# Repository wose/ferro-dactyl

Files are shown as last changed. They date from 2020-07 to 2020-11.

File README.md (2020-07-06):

# Ferro Dactyl

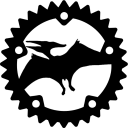
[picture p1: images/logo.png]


> A BluePill (STM32F103) based [Dactyl-Manuform] build with [keyberon] powered
> firmware written in Rust. 

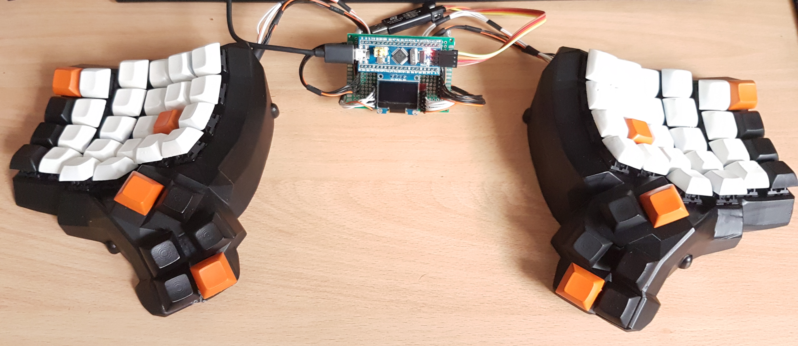
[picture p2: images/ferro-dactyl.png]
Ferro Dactyl


[Dactyl-Manuform]: https://github.com/20lives/Dactyl-Manuform
[keyberon]: https://github.com/TeXitoi/keyberon

## Layout

I'm using a [AdNW] based Layout. This is a work in progress.

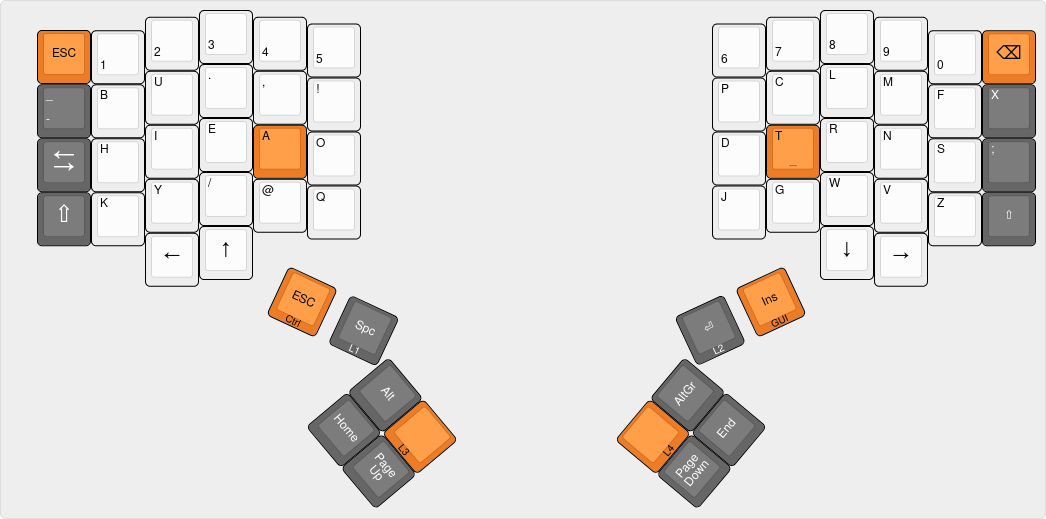
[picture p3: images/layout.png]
Layout


You can take the layout definition from the [layout folder] and play with it
over at [Keyboard Layout Editor]. Or use [this link].

[AdNW]: http://www.adnw.de/
[layout folder]:layout/
[Keyboard Layout Editor]: http://www.keyboard-layout-editor.com/
[this link]: http://www.keyboard-layout-editor.com/#/gists/5a7d56aa6b7ebb05c0e3928ac5250a80

## Hardware

The [STLs] are generated using [20lives Dactyl-Manuform fork]. I'm using a 5x6
version.

[STLs]: stl/
[20lives Dactyl-Manuform fork]:  https://github.com/20lives/Dactyl-Manuform

## Firmware

The firmware uses the [keyberon] library.

```shell
curl https://sh.rustup.rs -sSf | sh
rustup target add thumbv7m-none-eabi
sudo apt-get install gdb-arm-none-eabi openocd
git clone https://github.com/wose/ferro-dactyl.git
cd ferro-dactyl
# connect ST-Link v2 to the blue pill and the computer
# openocd in another terminal
cargo run --release
```
See `keyberons` [building instructions] for more info.

[building instructions]: https://github.com/TeXitoi/keyberon/blob/master/BUILDING.md

## License

Licensed under either of

- Apache License, Version 2.0 ([LICENSE-APACHE](LICENSE-APACHE) or
  http://www.apache.org/licenses/LICENSE-2.0)
- MIT license ([LICENSE-MIT](LICENSE-MIT) or http://opensource.org/licenses/MIT)

at your option.

### Contribution

Unless you explicitly state otherwise, any contribution intentionally submitted
for inclusion in the work by you, as defined in the Apache-2.0 license, shall be
dual licensed as above, without any additional terms or conditions.

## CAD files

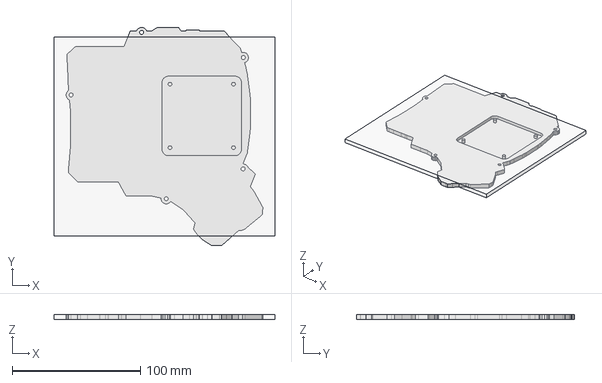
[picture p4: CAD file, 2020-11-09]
freecad/base.FCStd
172.4 x 170.4 x 4.00 mm
Stock001

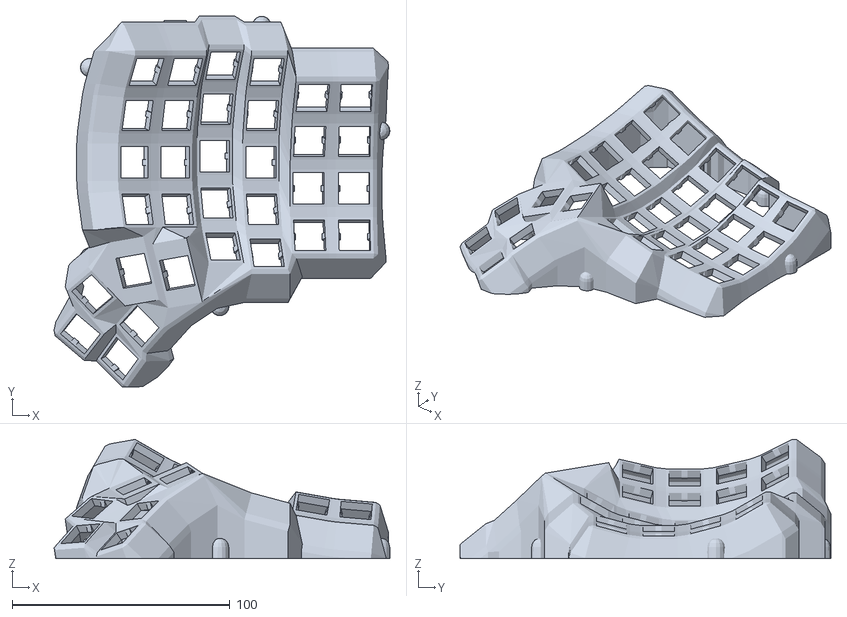
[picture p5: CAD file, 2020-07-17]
stl/right.stl
154.4 x 170.6 x 54.8

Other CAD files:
stl/left.stl

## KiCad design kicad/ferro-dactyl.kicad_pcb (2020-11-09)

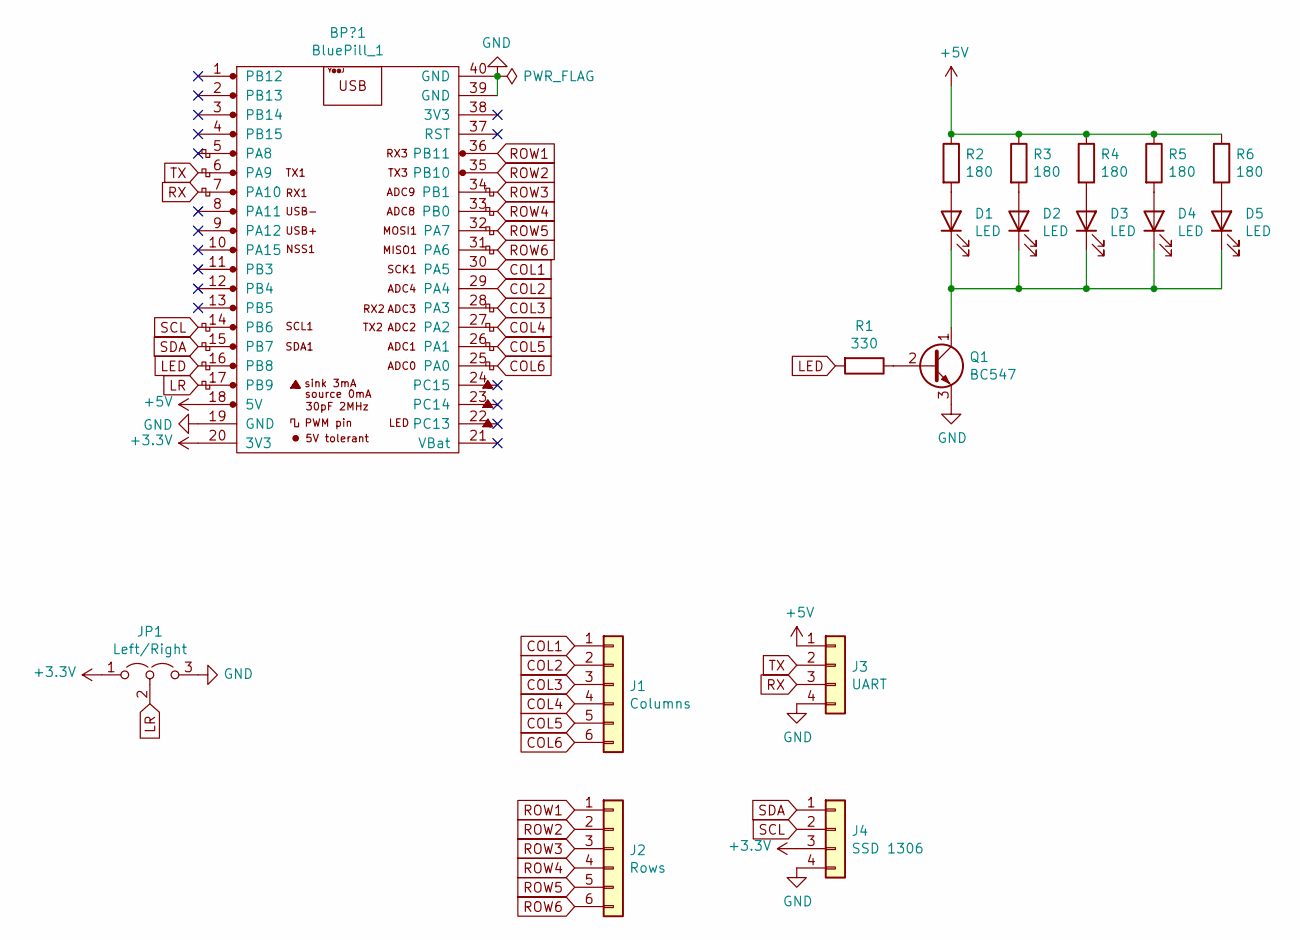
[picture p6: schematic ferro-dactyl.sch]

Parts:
BP?1: BluePill_1; YAAJ_BluePill_SWD_1
D1, D2, D3, D4, D5: LED; PinSocket_1x02_P2.54mm_Vertical
J1: Columns; PinSocket_1x06_P2.54mm_Vertical
J2: Rows; PinSocket_1x06_P2.54mm_Vertical
J3: UART; PinSocket_1x04_P2.54mm_Vertical
J4: SSD 1306; PinSocket_1x04_P2.54mm_Vertical
JP1: Left/Right; PinHeader_1x03_P2.54mm_Vertical
Q1: BC547; TO-92_Inline
R1: 330; R_Axial_DIN0411_L9.9mm_D3.6mm_P12.70mm_Horizontal
R2, R3, R4, R5, R6: 180; R_Axial_DIN0411_L9.9mm_D3.6mm_P12.70mm_Horizontal

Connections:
+3V3: BP?1.20 (3V3), J4.3, JP1.1 (A)
+5V: BP?1.18 (5V), J3.1, R2.1, R3.1, R4.1, R5.1, R6.1
COL1: BP?1.30 (PA5), J1.1
COL2: BP?1.29 (PA4), J1.2
COL3: BP?1.28 (PA3), J1.3
COL4: BP?1.27 (PA2), J1.4
COL5: BP?1.26 (PA1), J1.5
COL6: BP?1.25 (PA0), J1.6
GND: BP?1.19 (GND), BP?1.39 (GND), BP?1.40 (GND), J3.4, J4.4, JP1.3 (B), Q1.3 (E)
LED: BP?1.16 (PB8), R1.2
LR: BP?1.17 (PB9), JP1.2 (C)
unnamed: D1.1 (K), D2.1 (K), D3.1 (K), D4.1 (K), D5.1 (K), Q1.1 (C)
unnamed: D1.2 (A), R2.2
unnamed: D2.2 (A), R3.2
unnamed: D3.2 (A), R4.2
unnamed: D4.2 (A), R5.2
unnamed: D5.2 (A), R6.2
unnamed: Q1.2 (B), R1.1
ROW1: BP?1.36 (PB11), J2.1
ROW2: BP?1.35 (PB10), J2.2
ROW3: BP?1.34 (PB1), J2.3
ROW4: BP?1.33 (PB0), J2.4
ROW5: BP?1.32 (PA7), J2.5
ROW6: BP?1.31 (PA6), J2.6
RX: BP?1.7 (PA10), J3.3
SCL: BP?1.14 (PB6), J4.2
SDA: BP?1.15 (PB7), J4.1
TX: BP?1.6 (PA9), J3.2

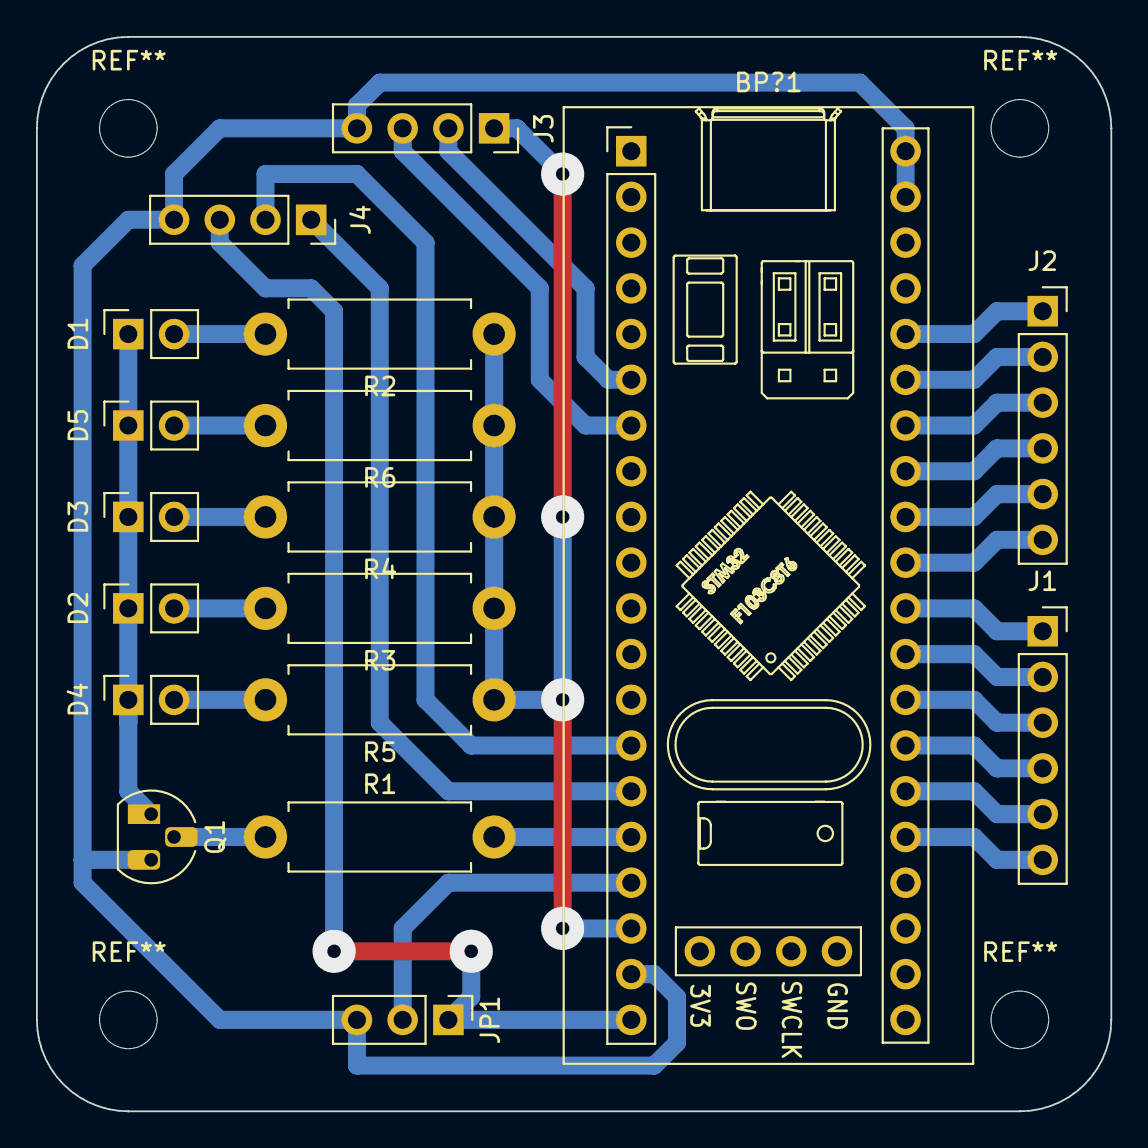
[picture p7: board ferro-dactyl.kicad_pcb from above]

Board: 2 copper layers, 59.7 x 59.7 mm, 18 parts (0 on the bottom side), 28 nets.

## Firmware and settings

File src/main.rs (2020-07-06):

#![no_main]
#![no_std]

use core::convert::Infallible;
use embedded_hal::digital::v2::{InputPin, OutputPin};
use generic_array::typenum::{U12, U6};
use keyberon::action::Action::{self, *};
use keyberon::action::{d, k, l, m};
use keyberon::debounce::Debouncer;
use keyberon::impl_heterogenous_array;
use keyberon::key_code::KeyCode::*;
use keyberon::key_code::{KbHidReport, KeyCode};
use keyberon::layout::Layout;
use keyberon::matrix::{Matrix, PressedKeys};
use panic_semihosting as _;
use rtfm::app;
use stm32f1xx_hal::gpio::{gpioa::*, gpiob::*, Input, Output, PullUp, PushPull};
use stm32f1xx_hal::prelude::*;
use stm32f1xx_hal::usb::{Peripheral, UsbBus, UsbBusType};
use stm32f1xx_hal::{gpio, pac, timer};
use usb_device::bus::UsbBusAllocator;
use usb_device::class::UsbClass as _;

type UsbClass = keyberon::Class<'static, UsbBusType, Leds>;
type UsbDevice = keyberon::Device<'static, UsbBusType>;

pub struct Leds {
    caps_lock: gpio::gpioc::PC13<gpio::Output<gpio::PushPull>>,
}
impl keyberon::keyboard::Leds for Leds {
    fn caps_lock(&mut self, status: bool) {
        if status {
            self.caps_lock.set_low().unwrap()
        } else {
            self.caps_lock.set_high().unwrap()
        }
    }
}

pub struct Cols(
    pub PB12<Input<PullUp>>,
    pub PB13<Input<PullUp>>,
    pub PB14<Input<PullUp>>,
    pub PB15<Input<PullUp>>,
    pub PA8<Input<PullUp>>,
    pub PA9<Input<PullUp>>,
    pub PA0<Input<PullUp>>,
    pub PA1<Input<PullUp>>,
    pub PA2<Input<PullUp>>,
    pub PA3<Input<PullUp>>,
    pub PA4<Input<PullUp>>,
    pub PA5<Input<PullUp>>,
);
impl_heterogenous_array! {
    Cols,
    dyn InputPin<Error = Infallible>,
    U12,
    [0, 1, 2, 3, 4, 5, 6, 7, 8, 9, 10, 11]
}

pub struct Rows(
    pub PB11<Output<PushPull>>,
    pub PB10<Output<PushPull>>,
    pub PB1<Output<PushPull>>,
    pub PB0<Output<PushPull>>,
    pub PA7<Output<PushPull>>,
    pub PA6<Output<PushPull>>,
);
impl_heterogenous_array! {
    Rows,
    dyn OutputPin<Error = Infallible>,
    U6,
    [0, 1, 2, 3, 4, 5]
}

// layer keys
const L1_SPACE: Action = HoldTap {
    timeout: 200,
    hold: &l(1),
    tap: &k(Space),
};

const L2_ENTER: Action = HoldTap {
    timeout: 200,
    hold: &l(2),
    tap: &k(Enter),
};

const CTRL_ESCAPE: Action = HoldTap {
    timeout: 200,
    hold: &k(LCtrl),
    tap: &k(Escape),
};

const GUI_INSERT: Action = HoldTap {
    timeout: 200,
    hold: &k(LGui),
    tap: &k(Insert),
};

const ALTGR_DELETE: Action = HoldTap {
    timeout: 200,
    hold: &k(RAlt),
    tap: &k(Delete),
};

// shifted symbols
const TILD: Action = m(&[LShift, NonUsHash]);
const EXLM: Action = m(&[LShift, Kb1]);
const AT: Action = m(&[LShift, Kb2]);
const HASH: Action = m(&[LShift, Kb3]);
const DLR: Action = m(&[LShift, Kb4]);
const PERC: Action = m(&[LShift, Kb5]);
const CIRC: Action = m(&[LShift, Kb6]);
const AMPR: Action = m(&[LShift, Kb7]);
const ASTR: Action = m(&[LShift, Kb8]);
const LPRN: Action = m(&[LShift, Kb9]);
const RPRN: Action = m(&[LShift, Kb0]);
const UNDS: Action = m(&[LShift, Minus]);
const PLUS: Action = m(&[LShift, Equal]);
const LCBR: Action = m(&[LShift, LBracket]);
const RCBR: Action = m(&[LShift, RBracket]);
const LT: Action = m(&[LShift, Comma]);
const GT: Action = m(&[LShift, Dot]);
const COLN: Action = m(&[LShift, SColon]);
const PIPE: Action = m(&[LShift, Bslash]);
const QUES: Action = m(&[LShift, Slash]);
const DQUO: Action = m(&[LShift, Quote]);

#[rustfmt::skip]
pub static LAYERS: keyberon::layout::Layers = &[
    &[
        &[k(Escape), k(Kb1), k(Kb2),    k(Kb3),   k(Kb4),      k(Kb5),          k(Kb6),    k(Kb7),     k(Kb8),  k(Kb9),      k(Kb0),   k(BSpace)],
        &[k(Minus),  k(B),   k(U),      k(Dot),   k(Comma),    EXLM,            k(P),      k(C),       k(L),    k(M),        k(F),     k(X)],
        &[k(Tab),    k(H),   k(I),      k(E),     k(A),        k(O),            k(D),      k(T),       k(R),    k(N),        k(S),     COLN],
        &[k(LShift), k(K),   k(Y),      k(Slash), AT,          k(Q),            k(J),      k(G),       k(W),    k(V),        k(Z),     k(RShift)],
        &[NoOp,      NoOp,   k(Left),   k(Up),    CTRL_ESCAPE, L1_SPACE,        L2_ENTER,  GUI_INSERT, k(Down), k(Right),    NoOp,     NoOp],
        &[NoOp,      NoOp,   k(PgUp),   l(3),     k(Home),     k(LAlt),         k(RAlt),   k(End),     l(4),    k(PgDown), NoOp,     NoOp],
    ],
    &[
        &[Trans, Trans, Trans, Trans, Trans, Trans,        Trans, Trans, Trans, Trans, Trans, Trans],
        &[Trans, Trans, Trans, Trans, Trans, Trans,        Trans, Trans, Trans, Trans, Trans, Trans],
        &[Trans, Trans, Trans, Trans, Trans, Trans,        Trans, Trans, Trans, Trans, Trans, Trans],
        &[Trans, Trans, Trans, Trans, Trans, Trans,        Trans, Trans, Trans, Trans, Trans, Trans],
        &[NoOp,  NoOp,  Trans, Trans, Trans, Trans,        Trans, Trans, Trans, Trans, NoOp,  NoOp],
        &[NoOp,  NoOp,  Trans, Trans, Trans, Trans,        Trans, Trans, Trans, Trans, NoOp,  NoOp],
    ],
    &[
        &[Trans, Trans, Trans, Trans, Trans, Trans,        Trans, Trans, Trans, Trans, Trans, Trans],
        &[Trans, Trans, Trans, Trans, Trans, Trans,        Trans, Trans, Trans, Trans, Trans, Trans],
        &[Trans, Trans, Trans, Trans, Trans, Trans,        Trans, Trans, Trans, Trans, Trans, Trans],
        &[Trans, Trans, Trans, Trans, Trans, Trans,        Trans, Trans, Trans, Trans, Trans, Trans],
        &[NoOp,  NoOp,  Trans, Trans, Trans, Trans,        Trans, Trans, Trans, Trans, NoOp,  NoOp],
        &[NoOp,  NoOp,  Trans, Trans, Trans, Trans,        Trans, Trans, Trans, Trans, NoOp,  NoOp],
    ],
    &[
        &[Trans, Trans, Trans, Trans, Trans, Trans,        Trans, Trans, Trans, Trans, Trans, Trans],
        &[Trans, Trans, Trans, Trans, Trans, Trans,        Trans, Trans, Trans, Trans, Trans, Trans],
        &[Trans, Trans, Trans, Trans, Trans, Trans,        Trans, Trans, Trans, Trans, Trans, Trans],
        &[Trans, Trans, Trans, Trans, Trans, Trans,        Trans, Trans, Trans, Trans, Trans, Trans],
        &[NoOp,  NoOp,  Trans, Trans, Trans, Trans,        Trans, Trans, Trans, Trans, NoOp,  NoOp],
        &[NoOp,  NoOp,  Trans, Trans, Trans, Trans,        Trans, Trans, Trans, Trans, NoOp,  NoOp],
    ],
    &[
        &[Trans, Trans, Trans, Trans, Trans, Trans,        Trans, Trans, Trans, Trans, Trans, Trans],
        &[Trans, Trans, Trans, Trans, Trans, Trans,        Trans, Trans, Trans, Trans, Trans, Trans],
        &[Trans, Trans, Trans, Trans, Trans, Trans,        Trans, Trans, Trans, Trans, Trans, Trans],
        &[Trans, Trans, Trans, Trans, Trans, Trans,        Trans, Trans, Trans, Trans, Trans, Trans],
        &[NoOp,  NoOp,  Trans, Trans, Trans, Trans,        Trans, Trans, Trans, Trans, NoOp,  NoOp],
        &[NoOp,  NoOp,  Trans, Trans, Trans, Trans,        Trans, Trans, Trans, Trans, NoOp,  NoOp],
    ],
];

#[app(device = stm32f1xx_hal::pac, peripherals = true)]
const APP: () = {
    struct Resources {
        usb_dev: UsbDevice,
        usb_class: UsbClass,
        matrix: Matrix<Cols, Rows>,
        debouncer: Debouncer<PressedKeys<U6, U12>>,
        layout: Layout,
        timer: timer::CountDownTimer<pac::TIM3>,
    }

    #[init]
    fn init(c: init::Context) -> init::LateResources {
        static mut USB_BUS: Option<UsbBusAllocator<UsbBusType>> = None;

        let mut flash = c.device.FLASH.constrain();
        let mut rcc = c.device.RCC.constrain();

        let clocks = rcc
            .cfgr
            .use_hse(8.mhz())
            .sysclk(48.mhz())
            .pclk1(24.mhz())
            .freeze(&mut flash.acr);

        let mut gpioa = c.device.GPIOA.split(&mut rcc.apb2);
        let mut gpiob = c.device.GPIOB.split(&mut rcc.apb2);
        let mut gpioc = c.device.GPIOC.split(&mut rcc.apb2);

        let mut led = gpioc.pc13.into_push_pull_output(&mut gpioc.crh);
        led.set_high().unwrap();
        let leds = Leds { caps_lock: led };

        let usb_dm = gpioa.pa11;
        let usb_dp = gpioa.pa12.into_floating_input(&mut gpioa.crh);

        let usb = Peripheral {
            usb: c.device.USB,
            pin_dm: usb_dm,
            pin_dp: usb_dp,
        };

        *USB_BUS = Some(UsbBus::new(usb));
        let usb_bus = USB_BUS.as_ref().unwrap();

        let usb_class = keyberon::new_class(usb_bus, leds);
        let usb_dev = keyberon::new_device(usb_bus);

        let mut timer =
            timer::Timer::tim3(c.device.TIM3, &clocks, &mut rcc.apb1).start_count_down(1.khz());
        timer.listen(timer::Event::Update);

        let matrix = Matrix::new(
            Cols(
                gpiob.pb12.into_pull_up_input(&mut gpiob.crh),
                gpiob.pb13.into_pull_up_input(&mut gpiob.crh),
                gpiob.pb14.into_pull_up_input(&mut gpiob.crh),
                gpiob.pb15.into_pull_up_input(&mut gpiob.crh),
                gpioa.pa8.into_pull_up_input(&mut gpioa.crh),
                gpioa.pa9.into_pull_up_input(&mut gpioa.crh),

                gpioa.pa0.into_pull_up_input(&mut gpioa.crl),
                gpioa.pa1.into_pull_up_input(&mut gpioa.crl),
                gpioa.pa2.into_pull_up_input(&mut gpioa.crl),
                gpioa.pa3.into_pull_up_input(&mut gpioa.crl),
                gpioa.pa4.into_pull_up_input(&mut gpioa.crl),
                gpioa.pa5.into_pull_up_input(&mut gpioa.crl),
            ),
            Rows(
                gpiob.pb11.into_push_pull_output(&mut gpiob.crh),
                gpiob.pb10.into_push_pull_output(&mut gpiob.crh),
                gpiob.pb1.into_push_pull_output(&mut gpiob.crl),
                gpiob.pb0.into_push_pull_output(&mut gpiob.crl),
                gpioa.pa7.into_push_pull_output(&mut gpioa.crl),
                gpioa.pa6.into_push_pull_output(&mut gpioa.crl),
            ),
        );

        init::LateResources {
            usb_dev,
            usb_class,
            timer,
            debouncer: Debouncer::new(PressedKeys::default(), PressedKeys::default(), 5),
            matrix: matrix.unwrap(),
            layout: Layout::new(LAYERS),
        }
    }

    #[task(binds = USB_HP_CAN_TX, priority = 2, resources = [usb_dev, usb_class])]
    fn usb_tx(mut c: usb_tx::Context) {
        usb_poll(&mut c.resources.usb_dev, &mut c.resources.usb_class);
    }

    #[task(binds = USB_LP_CAN_RX0, priority = 2, resources = [usb_dev, usb_class])]
    fn usb_rx(mut c: usb_rx::Context) {
        usb_poll(&mut c.resources.usb_dev, &mut c.resources.usb_class);
    }

    #[task(binds = TIM3, priority = 1, resources = [usb_class, matrix, debouncer, layout, timer])]
    fn tick(mut c: tick::Context) {
        c.resources.timer.clear_update_interrupt_flag();

        for event in c
            .resources
            .debouncer
            .events(c.resources.matrix.get().unwrap())
        {
            send_report(c.resources.layout.event(event), &mut c.resources.usb_class);
        }
        send_report(c.resources.layout.tick(), &mut c.resources.usb_class);
    }
};

fn send_report(iter: impl Iterator<Item = KeyCode>, usb_class: &mut resources::usb_class<'_>) {
    use rtfm::Mutex;
    let report: KbHidReport = iter.collect();
    if usb_class.lock(|k| k.device_mut().set_keyboard_report(report.clone())) {
        while let Ok(0) = usb_class.lock(|k| k.write(report.as_bytes())) {}
    }
}

fn usb_poll(usb_dev: &mut UsbDevice, keyboard: &mut UsbClass) {
    if usb_dev.poll(&mut [keyboard]) {
        keyboard.poll();
    }
}

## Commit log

2020-07-06 Adds STLs, layout and some images
    [left.stl, right.stl]
2020-07-07 Adds KiCAD project
    [ferro-dactyl.sch]
2020-07-11 Changes RJ9 connector to 3.5mm jack
    [left.stl, right.stl]
2020-07-17 Reduces wall thickness for jack mount
    [right.stl]
2020-11-09 Adds pcb
    [ferro-dactyl.kicad_pcb, ferro-dactyl.sch]
2020-11-09 Adds base plate FreeCAD project for CNC milling
    [base.FCStd]
